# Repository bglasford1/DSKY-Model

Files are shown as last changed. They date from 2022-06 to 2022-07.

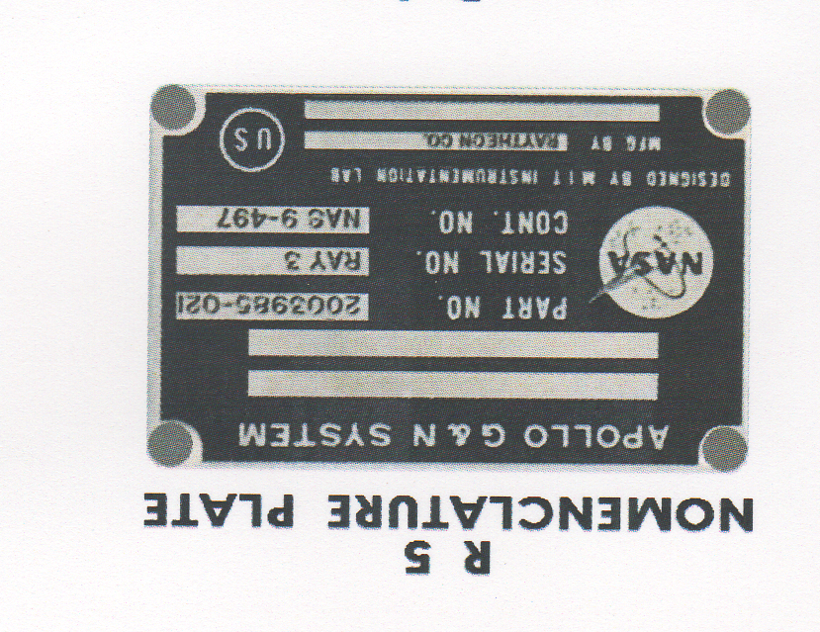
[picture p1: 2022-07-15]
NamePlate.tiff

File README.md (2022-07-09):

# DSKY-Model

This project works in conjunction with the AGC project.  The DSKY is the display/keyboard for the AGC.  As part of the AGC project, my first attempt at a DSKY was functional but not pretty.  I decided to 3D print an exact model of the DSKY and imbed the required electronics.  Instead of using LED indicators and 7-segment LEDs I chose to use a pair of LCD displays which makes the model much cleaner.  I could have placed the guts of the AGC DSKY into this model but I chose instead to drive the LCD displays and keyboard with three Arduino Nano Everys and drive those with a Raspberry Pi.  This gives me the ability to use this model as both a display for the AGC and as a standalone demonstrator by imbedding my simulator code.  The code will first look for a pulse on the CLK1 pin.  If the clock is present then it will use the Channel Bus and controls from the AGC.  If not it will start the simulator and run the simulation.  

To compile the Java code for the Raspberry Pi you need to include the pi4j (tested with version 1.2) and the jSerialComm (tested with version 2.9.1) libraries.
To compile the Arduino code you need to include the Adafruit_GFX and Adafruit_HX8357 libraries.

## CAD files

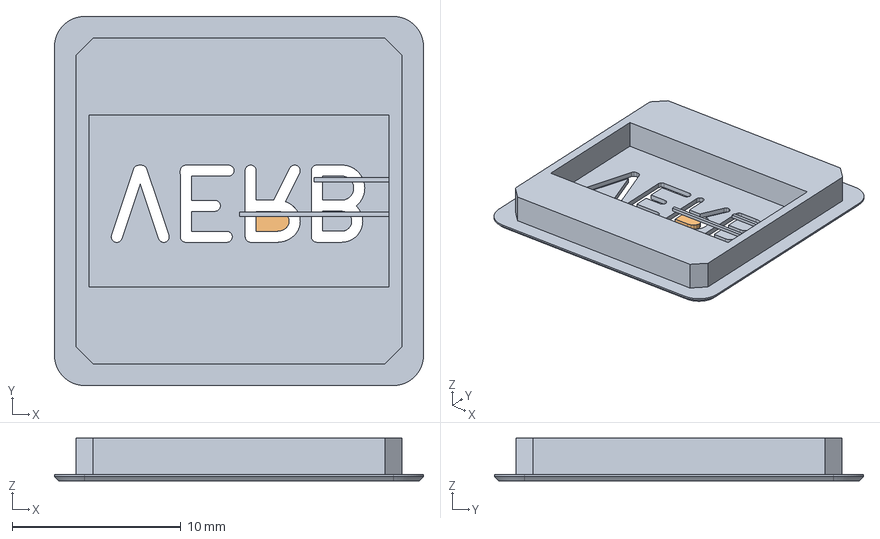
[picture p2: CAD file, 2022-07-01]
CAD/Keys/KeyVerb.step
21.8 x 21.8 x 2.54 mm

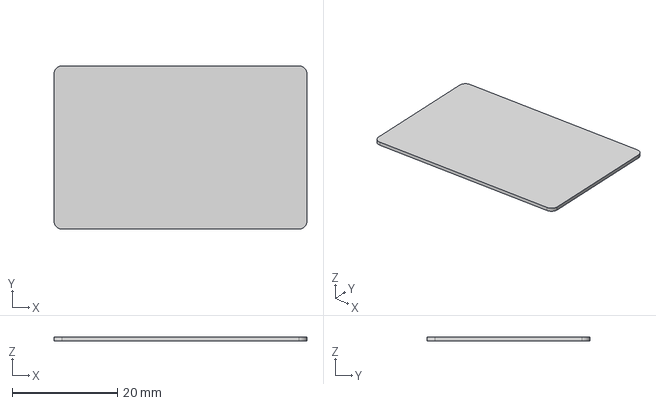
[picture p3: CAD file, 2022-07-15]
CAD/NamePlate.step
48.0 x 31.0 x 0.762 mm

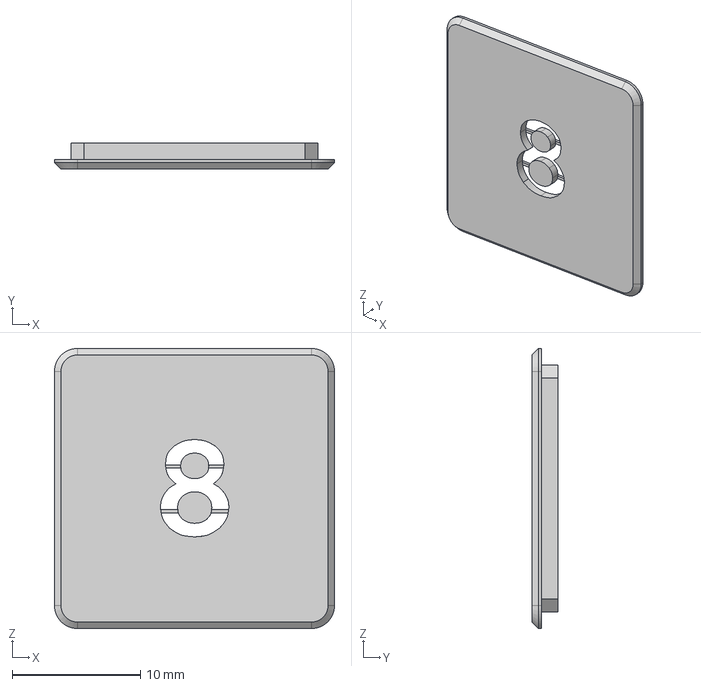
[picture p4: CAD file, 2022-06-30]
CAD/Keys/Key8.step
21.8 x 2.03 x 21.8 mm

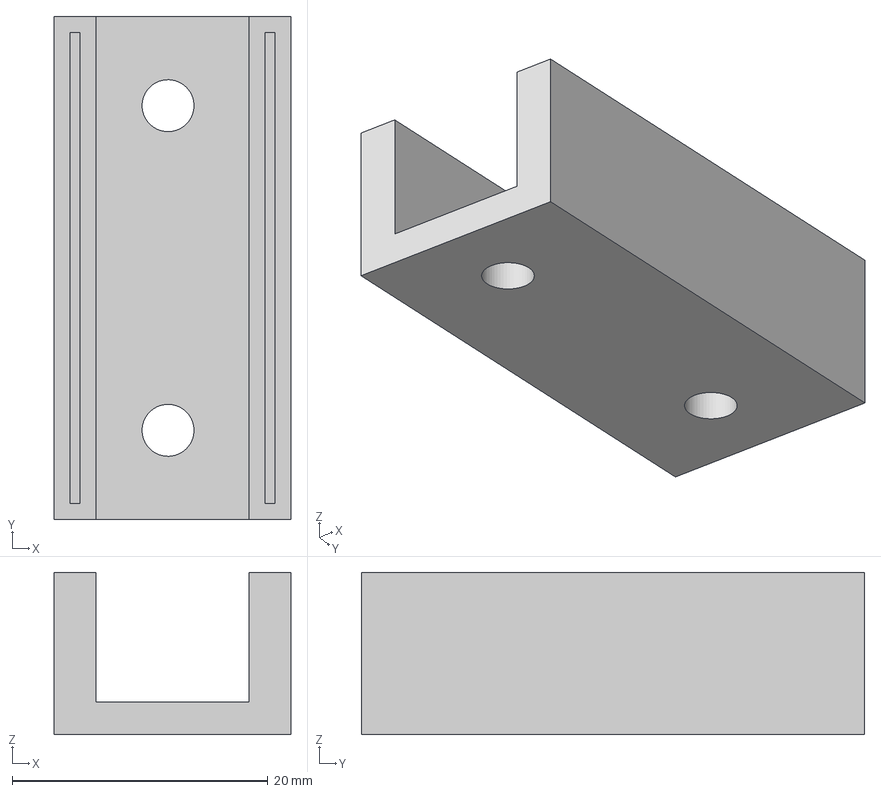
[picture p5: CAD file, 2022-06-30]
CAD/ArduinoMount.step
18.5 x 39.4 x 12.7 mm

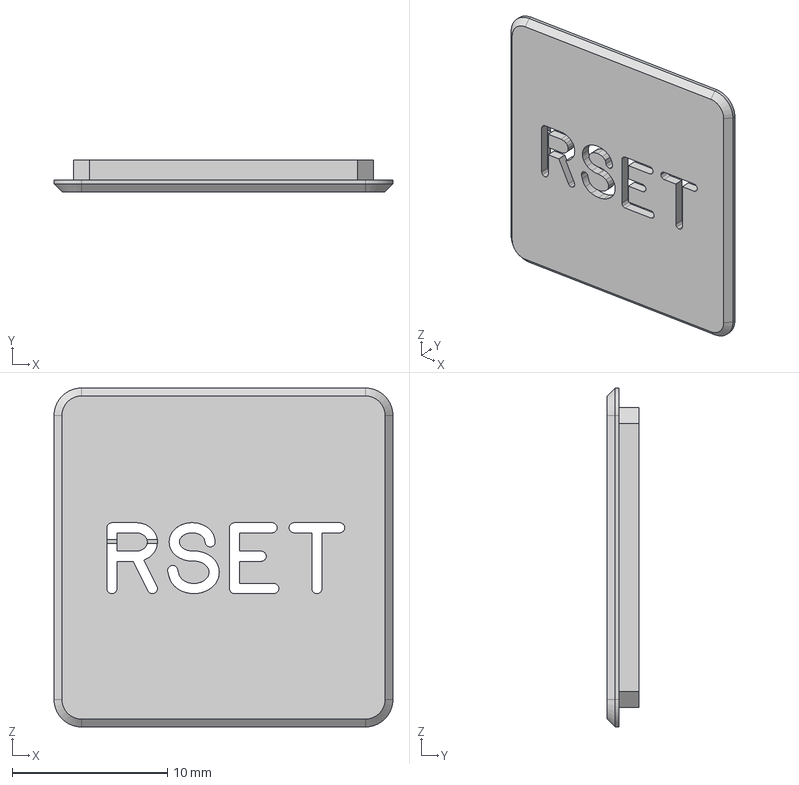
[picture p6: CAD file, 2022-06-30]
CAD/Keys/KeyReset.step
21.8 x 2.03 x 21.8 mm

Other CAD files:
CAD/Keys/KeyMinus.step
CAD/Keys/KeyPlus.step
CAD/Keys/KeyRelease.step
CAD/Keys/KeyProceed.step
CAD/Keys/KeyClear.step
CAD/Keys/KeyEnter.step
CAD/Keys/KeyNoun.step
CAD/Keys/Key7.step
CAD/Keys/Key2.step
CAD/Keys/Key3.step
CAD/Keys/Key4.step
CAD/Keys/Key5.step
CAD/Keys/Key1.step
CAD/1006315G-Modified.f3d
CAD/1006315G-Modified.step
CAD/1006349-exact-GASKET, RETAINED.f3d
CAD/1006349-exact-GASKET, RETAINED.step
CAD/1006350A-exact-GASKET, RETAINED.f3d
CAD/1006350A-exact-GASKET, RETAINED.step
CAD/1006351A-exact-GASKET.f3d
CAD/1006351A-exact-GASKET.step
CAD/2003926-reconstructed-HOUSING.step
CAD/2004699A-Modified.f3d
CAD/2004699A-Modified.step
CAD/2004900-exact-COVER,REAR.step
CAD/2004919E-modified-PLATE, ADAPTER.step
CAD/2004929-exact-COVER, FRONT.step
CAD/2004948B-modified-SHAFT.step
CAD/2004949D-exact-HOUSING.f3d
CAD/2004949D-exact-HOUSING.step
CAD/2004968E-modified.f3d
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

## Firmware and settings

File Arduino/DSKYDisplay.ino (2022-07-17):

/*
 * Copyright 2022, William Glasford
 *
 *  DSKY:
 *
 *  This is the Arduino code to run the 3.5" LCD that displays the main display of the DSKY.  
 *  This slave processor deals with the display minutia and does not store any state information.
 *  The code waits for a command from the higher level Raspberry Pi and executes the command.
 *  The display is 320 x 480 pixels in size.
 *
 * Mods:     07/04/22  Initial Release.
 *           07/16/22  Performance improvements.
 */
#include <SPI.h>
#include "Adafruit_GFX.h"
#include "Adafruit_HX8357.h"

// These are 'flexible' lines that can be changed
#define TFT_CS 8
#define TFT_DC 9
#define TFT_RST -1 // RST can be set to -1 if you tie it to Arduino's reset

#define BLACK 0x0000
#define GREEN 0x07E0 
#define WHITE 0xFFFF 
#define GREY 0x3186

#define CA_WIDTH 100
#define CA_HEIGHT 100
#define CA_COL 10
#define CA_ROW 0
#define CA_TEXT_X 38
#define CA_TEXT_Y1 30
#define CA_TEXT_Y2 50

#define PG_WIDTH 100
#define PG_HEIGHT 22
#define PG_COL 200
#define PG_ROW 0
#define PG_TEXT_X 225
#define PG_TEXT_Y 5

#define VB_WIDTH 100
#define VB_HEIGHT 22
#define VB_COL 10
#define VB_ROW 110
#define VB_TEXT_X 35
#define VB_TEXT_Y 113

#define NO_WIDTH 100
#define NO_HEIGHT 22
#define NO_COL 200
#define NO_ROW 110
#define NO_TEXT_X 225
#define NO_TEXT_Y 113

#define LINE_WIDTH 290
#define LINE_HEIGHT 7
#define LINE_COL 15
#define LINE_1_ROW 217
#define LINE_2_ROW 307
#define LINE_3_ROW 397

#define SIGN_WIDTH 30
#define SIGN_HEIGHT 10
#define R1S_ROW 261
#define R1S_COL 0
#define R2S_ROW 351
#define R2S_COL 0
#define R3S_ROW 441
#define R3S_COL 0

#define CHAR_WIDTH 45
#define CHAR_HEIGHT 70
#define CHAR_OFFSET 15
#define CHAR_BAR_WIDTH 8
#define CHAR_VOID_WIDTH 2

#define MD1_ROW 30
#define MD1_COL 195
#define MD2_ROW 30
#define MD2_COL 250

#define VD1_ROW 140
#define VD1_COL 0
#define VD2_ROW 140
#define VD2_COL 55

#define ND1_ROW 140
#define ND1_COL 195
#define ND2_ROW 140
#define ND2_COL 250

#define R1D1_ROW 230
#define R1D1_COL 30
#define R1D2_ROW 230
#define R1D2_COL 85
#define R1D3_ROW 230
#define R1D3_COL 140
#define R1D4_ROW 230
#define R1D4_COL 195
#define R1D5_ROW 230
#define R1D5_COL 250

#define R2D1_ROW 320
#define R2D1_COL 30
#define R2D2_ROW 320
#define R2D2_COL 85
#define R2D3_ROW 320
#define R2D3_COL 140
#define R2D4_ROW 320
#define R2D4_COL 195
#define R2D5_ROW 320
#define R2D5_COL 250

#define R3D1_ROW 410
#define R3D1_COL 30
#define R3D2_ROW 410
#define R3D2_COL 85
#define R3D3_ROW 410
#define R3D3_COL 140
#define R3D4_ROW 410
#define R3D4_COL 195
#define R3D5_ROW 410
#define R3D5_COL 250

#define R1S_PLUS  10
#define R1S_MINUS 11
#define R2S_PLUS  20
#define R2S_MINUS 21
#define R3S_PLUS  30
#define R3S_MINUS 31

// Use hardware SPI (on Uno, #13, #12, #11) and the above for CS/DC
Adafruit_HX8357 tft = Adafruit_HX8357(TFT_CS, TFT_DC, TFT_RST);

bool r1sPlus = false;
bool r1sMinus = false;
bool r2sPlus = false;
bool r2sMinus = false;
bool r3sPlus = false;
bool r3sMinus = false;

int vd1 = 0;
int vd2 = 0;
int nd1 = 0;
int nd2 = 0;

void setup() 
{
  String commandString;
  
  Serial.begin(9600);

  // Set up LCD
  tft.begin();
  tft.setRotation(2);

  resetDisplay();
  delay(500);

  // Wait for an initialize command.
  bool initialized = false;
  while (!initialized)
  {
    while (Serial.available()) 
    {
      delay(2);  // Delay 2 milliseconds to allow byte to arrive in input buffer
      char c = Serial.read();  // Gets one byte from serial buffer
    
      if (c != '\n' && c != '\r')  
        commandString += c; 
    }

    if (commandString.length() > 0 && commandString.equals("2"))
    {
      Serial.println("Display");
      initialized = true;
    }
    commandString = "";
  }
}

/*
 * This is the main Arduino loop that runs continuously.  It waits for a command from the 
 * Raspberry Pi, then executes the command before waiting for the next command.  Each 
 * command is followed by a number representing the 15-bit channel value.  The COMP ACTY 
 * is followed by 0 = off or 1 = on.  
 * The commands are:
 * 
 * 0  = Noop
 * 1  = Reset to power on state
 * 2  = Identify
 * 3  = Display Command
 * 4 = COMP ACTY
 * 5 = Flash Verb/Noun
 */
void loop() 
{
  String commandString;
  
  // Read the next command sequence.
  while (Serial.available()) 
  {
    delay(2);  // Delay 2 milliseconds to allow byte to arrive in input buffer
    char c = Serial.read();  // Gets one byte from serial buffer
    
    if (c != '\n')  
      commandString += c; 
  }

  // If there is a command string to parse...
  if (commandString.length() > 0) 
  {
    String command = commandString;
    String data = "";
    String delim = " ";
    int number;
    byte dspl;
    byte dsph;
    byte rlwd;
    bool signValue = false;

    // Parse the command string.
    if (commandString != "0" && commandString != "1" && commandString != "2")
    {
      int firstDelimIndex = commandString.indexOf(delim);
      command = commandString.substring(0, firstDelimIndex);
      data = commandString.substring(firstDelimIndex + 1);
      int intValue = data.toInt();
      Serial.println(intValue);
      rlwd = (intValue >> 11) & 0x000F;
      dspl = intValue & 0x001F;
      dsph = (intValue >> 5) & 0x001F;
      signValue = (intValue >> 10) & 0x0001;
     }
    
    // Process the Reset command.
    if (command == "1")
    {
      resetDisplay();
    }

    // Process the MD1/MD2 command.
    else if (command == "3")
    {
      if (rlwd == 11)
      {
        displayCharacter(dsph, MD1_COL, MD1_ROW);
        displayCharacter(dspl, MD2_COL, MD2_ROW);
      }
      else if (rlwd == 10)
      {
        vd1 = dspl;
        vd2 = dsph;
        displayCharacter(dsph, VD1_COL, VD1_ROW);
        displayCharacter(dspl, VD2_COL, VD2_ROW);
      }
      else if (rlwd == 9)
      {
        nd1 = dspl;
        nd2 = dsph;
        displayCharacter(dsph, ND1_COL, ND1_ROW);
        displayCharacter(dspl, ND2_COL, ND2_ROW);
      }
      else if (rlwd == 8)
      {
        displayCharacter(dspl, R1D1_COL, R1D1_ROW);
      }
      else if (rlwd == 7)
      {
        if (signValue)
        {
          r1sPlus = true;
          if (!r1sMinus)
          {
            displayPlus(R1S_COL, R1S_ROW);
          }
        }
        else
        {
          r1sPlus = false;
          if (!r1sMinus)
          {
            displayBlank(R1S_COL, R1S_ROW);
          }
        }
        displayCharacter(dsph, R1D2_COL, R1D2_ROW);
        displayCharacter(dspl, R1D3_COL, R1D3_ROW);
      }
      else if (rlwd == 6)
      {
        if (signValue)
        {
          r1sMinus = true;
          if (!r1sPlus)
          {
            displayMinus(R1S_COL, R1S_ROW);
          }
        }
        else
        {
          r1sMinus = false;
          if (!r1sPlus)
          {
            displayBlank(R1S_COL, R1S_ROW);
          }
        }
        displayCharacter(dsph, R1D4_COL, R1D4_ROW);
        displayCharacter(dspl, R1D5_COL, R1D5_ROW);
      }
      else if (rlwd == 5)
      {
        if (signValue)
        {
          r2sPlus = true;
          if (!r2sMinus)
          {
            displayPlus(R2S_COL, R2S_ROW);
          }
        }
        else
        {
          r2sPlus = false;
          if (!r2sMinus)
          {
            displayBlank(R2S_COL, R2S_ROW);
          }
        }
        displayCharacter(dsph, R2D1_COL, R2D1_ROW);
        displayCharacter(dspl, R2D2_COL, R2D2_ROW);
      }
      else if (rlwd == 4)
      {
        if (signValue)
        {
          r2sMinus = true;
          if (!r2sPlus)
          {
            displayMinus(R2S_COL, R2S_ROW);
          }
        }
        else
        {
          r2sMinus = false;
          if (!r2sPlus)
          {
            displayBlank(R2S_COL, R2S_ROW);
          }
        }
        displayCharacter(dsph, R2D3_COL, R2D3_ROW);
        displayCharacter(dspl, R2D4_COL, R2D4_ROW);
      }
      else if (rlwd == 3)
      {
        displayCharacter(dsph, R2D5_COL, R2D5_ROW);
        displayCharacter(dspl, R3D1_COL, R3D1_ROW);
      }
      else if (rlwd == 2)
      {
        if (signValue)
        {
          r3sPlus = true;
          if (!r3sMinus)
          {
            displayPlus(R3S_COL, R3S_ROW);
          }
        }
        else
        {
          r3sPlus = false;
          if (!r3sMinus)
          {
            displayBlank(R3S_COL, R3S_ROW);
          }
        }
        displayCharacter(dsph, R3D2_COL, R3D2_ROW);
        displayCharacter(dspl, R3D3_COL, R3D3_ROW);
      }
      else if (rlwd == 1)
      {
        if (signValue)
        {
          r3sMinus = true;
          if (!r3sPlus)
          {
            displayMinus(R3S_COL, R3S_ROW);
          }
        }
        else
        {
          r3sMinus = false;
          if (!r3sPlus)
          {
            displayBlank(R3S_COL, R3S_ROW);
          }
        }
        displayCharacter(dsph, R3D4_COL, R3D4_ROW);
        displayCharacter(dspl, R3D5_COL, R3D5_ROW);
      }
    }

    // Process the COMP ACTY command.
    else if (command == "4")
    {
      if (data == "0")
      {
        displayCompActy(false);
      }
      else
      {
        displayCompActy(true);
      }
    }

    // Process Flash Verb/Noun command.
    else if (command = "5")
    {
      if (data == "0")
      {
        displayCharacter(0, VD1_COL, VD1_ROW);
        displayCharacter(0, VD2_COL, VD2_ROW);
        displayCharacter(0, ND1_COL, ND1_ROW);
        displayCharacter(0, ND2_COL, ND2_ROW);
      }
      else 
      {
        displayCharacter(vd1, VD1_COL, VD1_ROW);
        displayCharacter(vd2, VD2_COL, VD2_ROW);
        displayCharacter(nd1, ND1_COL, ND1_ROW);
        displayCharacter(nd2, ND2_COL, ND2_ROW);
      }
    }

    commandString = "";
  }
}

/*
 * Reset the display to a power on state.
 */
void resetDisplay()
{
  tft.fillScreen(BLACK);  
  tft.setTextColor(BLACK);
  tft.setTextSize(2);

  // Display PROG 
  tft.fillRect(PG_COL, PG_ROW, PG_WIDTH, PG_HEIGHT, GREEN);
  
  tft.setTextColor(BLACK);
  tft.setTextSize(2);
    
  tft.setCursor(PG_TEXT_X, PG_TEXT_Y);
  tft.println("PROG");

  // Display VERB 
  tft.fillRect(VB_COL, VB_ROW, VB_WIDTH, VB_HEIGHT, GREEN);
  
  tft.setTextColor(BLACK);
  tft.setTextSize(2);
    
  tft.setCursor(VB_TEXT_X, VB_TEXT_Y);
  tft.println("VERB");

  // Display NOUN 
  tft.fillRect(NO_COL, NO_ROW, PG_WIDTH, NO_HEIGHT, GREEN);
  
  tft.setTextColor(BLACK);
  tft.setTextSize(2);
    
  tft.setCursor(NO_TEXT_X, NO_TEXT_Y);
  tft.println("NOUN");

  // Display Lines 
  tft.fillRect(LINE_COL, LINE_1_ROW, LINE_WIDTH, LINE_HEIGHT, GREEN);
  tft.fillRect(LINE_COL, LINE_2_ROW, LINE_WIDTH, LINE_HEIGHT, GREEN);
  tft.fillRect(LINE_COL, LINE_3_ROW, LINE_WIDTH, LINE_HEIGHT, GREEN);

  displayCompActy(false);
}

/*
 * Turn on/off the Computer Activity light.  
 */
void displayCompActy(bool state)
{
  if (state)
  {
    tft.fillRect(CA_COL, CA_ROW, CA_WIDTH, CA_HEIGHT, GREEN);
  }
  else
  {
    tft.fillRect(CA_COL, CA_ROW, CA_WIDTH, CA_HEIGHT, GREY);
  }
    
  tft.setCursor(CA_TEXT_X, CA_TEXT_Y1);
  tft.println("COMP");
 
  tft.setCursor(CA_TEXT_X, CA_TEXT_Y2);
  tft.println("ACTY");
}

/*
 * Display the character based on home position (upper left corner).  There are two triangles used
 * to draw each segment.  The first one draws from UL, LL & LR.  The second one draws from UL, UR & LR.
 */
 void displayCharacter(byte number, int x, int y)
 {
  // Display based on character to display.
  if (number == 0x00) // Blank
  {
    drawSegmentA(x, y, BLACK);
    drawSegmentB(x, y, BLACK);
    drawSegmentC(x, y, BLACK);
    drawSegmentD(x, y, BLACK);
    drawSegmentE(x, y, BLACK);
    drawSegmentF(x, y, BLACK);
    drawSegmentG(x, y, BLACK);
  }
  else if (number == 0x15) // 0
  {
    drawSegmentA(x, y, GREEN);
    drawSegmentB(x, y, GREEN);
    drawSegmentC(x, y, GREEN);
    drawSegmentD(x, y, GREEN);
    drawSegmentE(x, y, GREEN);
    drawSegmentF(x, y, GREEN);
    drawSegmentG(x, y, BLACK);
  }
  else if (number == 0x03) // 1
  {
    drawSegmentA(x, y, BLACK);
    drawSegmentB(x, y, GREEN);
    drawSegmentC(x, y, GREEN);
    drawSegmentD(x, y, BLACK);
    drawSegmentE(x, y, BLACK);
    drawSegmentF(x, y, BLACK);
    drawSegmentG(x, y, BLACK);
  }
  else if (number == 0x19) // 2
  {
    drawSegmentA(x, y, GREEN);
    drawSegmentB(x, y, GREEN);
    drawSegmentC(x, y, BLACK);
    drawSegmentE(x, y, GREEN);
    drawSegmentD(x, y, GREEN);
    drawSegmentF(x, y, BLACK);
    drawSegmentG(x, y, GREEN);
  }
  else if (number == 0x1B) // 3
  {
    drawSegmentA(x, y, GREEN);
    drawSegmentB(x, y, GREEN);
    drawSegmentC(x, y, GREEN);
    drawSegmentD(x, y, GREEN);
    drawSegmentE(x, y, BLACK);
    drawSegmentF(x, y, BLACK);
    drawSegmentG(x, y, GREEN);
  }
  else if (number == 0x0F) // 4
  {
    drawSegmentA(x, y, BLACK);
    drawSegmentB(x, y, GREEN);
    drawSegmentC(x, y, GREEN);
    drawSegmentD(x, y, BLACK);
    drawSegmentE(x, y, BLACK);
    drawSegmentF(x, y, GREEN);
    drawSegmentG(x, y, GREEN);
  }
  else if (number == 0x1E) // 5
  {
    drawSegmentA(x, y, GREEN);
    drawSegmentB(x, y, BLACK);
    drawSegmentC(x, y, GREEN);
    drawSegmentD(x, y, GREEN);
    drawSegmentE(x, y, BLACK);
    drawSegmentF(x, y, GREEN);
    drawSegmentG(x, y, GREEN);
  }
  else if (number == 0x1C) // 6
  {
    drawSegmentA(x, y, GREEN);
    drawSegmentB(x, y, BLACK);
    drawSegmentC(x, y, GREEN);
    drawSegmentD(x, y, GREEN);
    drawSegmentE(x, y, GREEN);
    drawSegmentF(x, y, GREEN);
    drawSegmentG(x, y, GREEN);
  }
  else if (number == 0x13) // 7
  {
    drawSegmentA(x, y, GREEN);
    drawSegmentB(x, y, GREEN);
    drawSegmentC(x, y, GREEN);
    drawSegmentD(x, y, BLACK);
    drawSegmentE(x, y, BLACK);
    drawSegmentF(x, y, BLACK);
    drawSegmentG(x, y, BLACK);
  }
  else if (number == 0x1D) // 8
  {
    drawSegmentA(x, y, GREEN);
    drawSegmentB(x, y, GREEN);
    drawSegmentC(x, y, GREEN);
    drawSegmentD(x, y, GREEN);
    drawSegmentE(x, y, GREEN);
    drawSegmentF(x, y, GREEN);
    drawSegmentG(x, y, GREEN);
  }
  else if (number == 0x1F) // 9
  {
    drawSegmentA(x, y, GREEN);
    drawSegmentB(x, y, GREEN);
    drawSegmentC(x, y, GREEN);
    drawSegmentD(x, y, BLACK);
    drawSegmentE(x, y, BLACK);
    drawSegmentF(x, y, GREEN);
    drawSegmentG(x, y, GREEN);
  }
  else
  {
    displayCompActy(true);
  }
}

/*
 * Draw the A segment of the 7-segment LED.
 */
void drawSegmentA (int x, int y, int color)
{
  tft.fillTriangle (x + CHAR_OFFSET + 1, y, 
                    x + CHAR_OFFSET + CHAR_BAR_WIDTH, y + CHAR_BAR_WIDTH, 
                    x + CHAR_OFFSET + CHAR_WIDTH - CHAR_BAR_WIDTH - 2, y + CHAR_BAR_WIDTH, color);
 
  tft.fillTriangle (x + CHAR_OFFSET + 1, y,
                    x + CHAR_OFFSET + CHAR_WIDTH - CHAR_BAR_WIDTH - 2, y, 
                    x + CHAR_OFFSET + CHAR_WIDTH - CHAR_BAR_WIDTH - 4, y + CHAR_BAR_WIDTH, color); 
}

/*
 * Draw the B segment of the 7-segment LED.
 */
void drawSegmentB (int x, int y, int color)
{
  tft.fillTriangle (x + CHAR_OFFSET + CHAR_WIDTH - CHAR_BAR_WIDTH, y, 
                    x + CHAR_WIDTH, y + 34, 
                    x + CHAR_WIDTH + CHAR_BAR_WIDTH, y + 34, color);
 
  tft.fillTriangle (x + CHAR_OFFSET + CHAR_WIDTH - CHAR_BAR_WIDTH, y,
                    x + CHAR_OFFSET + CHAR_WIDTH, y, 
                    x + CHAR_WIDTH + CHAR_BAR_WIDTH, y + 34, color);
}

/*
 * Draw the C segment of the 7-segment LED.
 */
void drawSegmentC (int x, int y, int color)
{
  tft.fillTriangle (x + CHAR_OFFSET + CHAR_WIDTH - CHAR_BAR_WIDTH - 8, y + 36, 
                    x + CHAR_WIDTH - CHAR_BAR_WIDTH + 2, y + CHAR_HEIGHT - CHAR_BAR_WIDTH - 2, 
                    x + CHAR_WIDTH, y + CHAR_HEIGHT, color);
 
  tft.fillTriangle (x + CHAR_OFFSET + CHAR_WIDTH - CHAR_BAR_WIDTH - 8, y + 36,
                    x + CHAR_OFFSET + CHAR_WIDTH - 7, y + 36, 
                    x + CHAR_WIDTH, y + CHAR_HEIGHT, color);
}

/*
 * Draw the D segment of the 7-segment LED.
 */
void drawSegmentD (int x, int y, int color)
{
  tft.fillTriangle (x + CHAR_BAR_WIDTH + 4, y + CHAR_HEIGHT - CHAR_BAR_WIDTH, 
                    x + 2, y + CHAR_HEIGHT, 
                    x + CHAR_WIDTH - 2, y + CHAR_HEIGHT, color);
 
  tft.fillTriangle (x + CHAR_BAR_WIDTH + 4, y + CHAR_HEIGHT - CHAR_BAR_WIDTH,
                    x + CHAR_WIDTH - CHAR_BAR_WIDTH, y + CHAR_HEIGHT - CHAR_BAR_WIDTH, 
                    x + CHAR_WIDTH - 2, y + CHAR_HEIGHT, color);
}

/*
 * Draw the E segment of the 7-segment LED.
 */
void drawSegmentE (int x, int y, int color)
{
  tft.fillTriangle (x + 7, y + 36, 
                    x, y + CHAR_HEIGHT - 1, 
                    x + CHAR_BAR_WIDTH + 1, y + CHAR_HEIGHT - CHAR_BAR_WIDTH, color);
 
  tft.fillTriangle (x + 7, y + 36,
                    x + CHAR_BAR_WIDTH + 7, y + 36, 
                    x + CHAR_BAR_WIDTH + 1, y + CHAR_HEIGHT - CHAR_BAR_WIDTH, color);
}

/*
 * Draw the F segment of the 7-segment LED.
 */
void drawSegmentF (int x, int y, int color)
{
  tft.fillTriangle (x + CHAR_OFFSET - 1, y, 
                    x + 7, y + 34, 
                    x + CHAR_BAR_WIDTH + 7, y + 34, color);
 
  tft.fillTriangle (x + CHAR_OFFSET - 1, y,
                    x + CHAR_OFFSET + CHAR_BAR_WIDTH - 2, y + CHAR_BAR_WIDTH + 2, 
                    x + CHAR_BAR_WIDTH + 7, y + 34, color);
}

/*
 * Draw the G segment of the 7-segment LED.
 */
void drawSegmentG (int x, int y, int color)
{
  tft.fillTriangle (x + CHAR_OFFSET + CHAR_BAR_WIDTH - 4, y + 31, 
                    x + CHAR_OFFSET + CHAR_BAR_WIDTH - 6, y + 39, 
                    x + CHAR_WIDTH - CHAR_BAR_WIDTH + 4, y + 39, color);
 
  tft.fillTriangle (x + CHAR_OFFSET + CHAR_BAR_WIDTH - 4, y + 31,
                    x + CHAR_WIDTH - CHAR_BAR_WIDTH + 6, y + 31, 
                    x + CHAR_WIDTH - CHAR_BAR_WIDTH + 4, y + 39, color);
}

/*
 * Display the plus sign.
 */
void displayPlus (int x, int y)
{
  tft.fillRect(x, y, SIGN_WIDTH, SIGN_HEIGHT, GREEN);
  tft.fillRect(x + 11, y - 17, 8, 14, GREEN);
  tft.fillRect(x + 11, y + 13, 8, 14, GREEN);
}

/*
 * Display the minus sign.
 */
void displayMinus (int x, int y)
{
  tft.fillRect(x, y, SIGN_WIDTH, SIGN_HEIGHT, GREEN);
  tft.fillRect(x + 11, y - 17, 8, 14, BLACK);
  tft.fillRect(x + 11, y + 13, 8, 14, BLACK);
}

/*
 * Blank the sign.
 */
void displayBlank (int x, int y)
{
  tft.fillRect(x, y, SIGN_WIDTH, SIGN_HEIGHT, BLACK);
  tft.fillRect(x + 11, y - 17, 8, 14, BLACK);
  tft.fillRect(x + 11, y + 13, 8, 14, BLACK);
}

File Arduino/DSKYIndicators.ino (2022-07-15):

/*
 * Copyright 2022, William Glasford
 *
 *  DSKY:
 *
 *  This is the Arduino code to run the 3.5" LCD that displays the indicators of the DSKY.  
 *  This slave processor deals with the display minutia and does not store any state information.
 *  The code waits for a command from the higher level Raspberry Pi and executes the command.
 *
 * Mods:     07/04/22  Initial Release.
 *           07/15/22  Simplified commands to take 6 indicators at a time.
 */
#include <SPI.h>
#include "Adafruit_GFX.h"
#include "Adafruit_HX8357.h"

// These are 'flexible' lines that can be changed
#define TFT_CS 8
#define TFT_DC 9
#define TFT_RST -1 // RST can be set to -1 if you tie it to Arduino's reset

// LCD colors: RGB: 16-bit value from MSB to LSB: RRRRRGGGGGGBBBBB
#define BLACK 0x0000
#define WHITE 0xFFFF 
#define GREY 0x3186
#define YELLOW 0xFFE0

#define BOX_WIDTH 156
#define BOX_HEIGHT 60
#define START_COL1 0
#define START_COL2 164
#define START_ROW1 0
#define START_ROW2 68
#define START_ROW3 136
#define START_ROW4 204
#define START_ROW5 272
#define START_ROW6 340
#define START_ROW7 408
#define TEXT_UPPER_ROW 15
#define TEXT_LOWER_ROW 35
#define TEXT_CENTERED 25
#define TEXT_SHORT 60
#define TEXT_MEDIUM 55
#define TEXT_LONG 45
#define TEXT_XLONG 35

// Use hardware SPI (on Uno, #13, #12, #11) and the above for CS/DC
Adafruit_HX8357 tft = Adafruit_HX8357(TFT_CS, TFT_DC, TFT_RST);

// SoftSPI - note that on some processors this might be *faster* than hardware SPI!
//Adafruit_HX8357 tft = Adafruit_HX8357(TFT_CS, TFT_DC, MOSI, SCK, TFT_RST, MISO);

int savedDisplayIndicators = 0;
int savedOtherIndicators = 0;

void setup() 
{
  String commandString;
  
  Serial.begin(9600);

  // TODO: Set up LCD
  tft.begin();
  tft.setRotation(2);

  resetDisplay();
  delay(100);

  // Wait for an initialize command.
  bool initialized = false;
  while (!initialized)
  {
    while (Serial.available()) 
    {
      delay(2);  // Delay 2 milliseconds to allow byte to arrive in input buffer
      char c = Serial.read();  // Gets one byte from serial buffer
    
      if (c != '\n' && c != '\r')  
        commandString += c; 
    }

    if (commandString.length() > 0 && commandString.equals("2"))
    {
      Serial.println("Indicators");
      initialized = true;
    }
    commandString = "";
  }
}

/*
 * This is the main Arduino loop that runs continuously.  It waits for a command from the 
 * Raspberry Pi, then executes the command before waiting for the next command.  Commands 
 * 3 & 4 are followed by an integer string that represents the bits as defined below.
 * The commands are:
 * 0  = Noop
 * 1  = Reset to power on state
 * 2  = Identify
 * 3  = Display Indicators
 *        Bit 0 = NO ATT
 *        Bit 1 = GIMBAL LOCK
 *        Bit 2 = PROG
 *        Bit 3 = TRACKER
 *        Bit 4 = ALT
 *        Bit 5 = VEL
 * 4  = Other Indicators
 *        Bit 0 = UPLINK ACTY
 *        Bit 1 = KEY REL
 *        Bit 2 = OPR ERR
 *        Bit 3 = TEMP
 *        Bit 4 = STBY
 *        Bit 5 = RESTART
 */
void loop() 
{
  String commandString;

  // Read the next command sequence.
  while (Serial.available() > 0) 
  {
    delay(2);  // Delay 2 milliseconds to allow byte to arrive in input buffer
    char c = Serial.read();  // Gets one byte from serial buffer
    
    if (c != '\n' && c != '\r')  
      commandString += c; 
  }

  // If there is a command string to parse...
  if (commandString.length() > 0) 
  {
    String command = commandString;
    String data = "";
    String delim = " ";

    // Parse the command string.
    if (commandString != "0" && commandString != "1" && commandString != "2")
    {
      int firstDelimIndex = commandString.indexOf(delim);
      command = commandString.substring(0, firstDelimIndex);
      data = commandString.substring(firstDelimIndex + 1, commandString.length());
    }
    
    // Process the Reset command.
    if (command == "1")
    {
     resetDisplay();
    }
    
    // Process the Display Indicators command.
    else if (command == "3")
    {
      byte newDisplayValue = (byte)data.toInt();
      byte bitZero  = newDisplayValue & 0x01;
      byte bitOne   = (newDisplayValue >> 1) & 0x01;
      byte bitTwo   = (newDisplayValue >> 2) & 0x01;
      byte bitThree = (newDisplayValue >> 3) & 0x01;
      byte bitFour  = (newDisplayValue >> 4) & 0x01;
      byte bitFive  = (newDisplayValue >> 5) & 0x01;
      
      byte oldBitZero  = savedDisplayIndicators & 0x01;
      byte oldBitOne   = (savedDisplayIndicators >> 1) & 0x01;
      byte oldBitTwo   = (savedDisplayIndicators >> 2) & 0x01;
      byte oldBitThree = (savedDisplayIndicators >> 3) & 0x01;
      byte oldBitFour  = (savedDisplayIndicators >> 4) & 0x01;
      byte oldBitFive  = (savedDisplayIndicators >> 5) & 0x01;

      if (bitZero != oldBitZero)
      {
        drawNOATT(bitZero);
      }
      if (bitOne != oldBitOne)
      {
        drawGIMBALLOCK(bitOne);
      }
      if (bitTwo != oldBitTwo)
      {
        drawPROG(bitTwo);
      }
      if (bitThree != oldBitThree)
      {
        drawTRACKER(bitThree);
      }
      if (bitFour != oldBitFour)
      {
        drawALT(bitFour);
      }
      if (bitFive != oldBitFive)
      {
        drawVEL(bitFive);
      }
      savedDisplayIndicators = newDisplayValue;
    }

    // Process the Other Indicators command.
    else if (command == "4")
    {
      byte newOtherValue = (byte)data.toInt();
      byte bitZero  = newOtherValue & 0x01;
      byte bitOne   = (newOtherValue >> 1) & 0x01;
      byte bitTwo   = (newOtherValue >> 2) & 0x01;
      byte bitThree = (newOtherValue >> 3) & 0x01;
      byte bitFour  = (newOtherValue >> 4) & 0x01;
      byte bitFive  = (newOtherValue >> 5) & 0x01;
      
      byte oldBitZero  = savedOtherIndicators & 0x01;
      byte oldBitOne   = (savedOtherIndicators >> 1) & 0x01;
      byte oldBitTwo   = (savedOtherIndicators >> 2) & 0x01;
      byte oldBitThree = (savedOtherIndicators >> 3) & 0x01;
      byte oldBitFour  = (savedOtherIndicators >> 4) & 0x01;
      byte oldBitFive  = (savedOtherIndicators >> 5) & 0x01;

      if (bitZero != oldBitZero)
      {
        drawUPLINKACTY(bitZero);
      }
      if (bitOne != oldBitOne)
      {
        drawKEYREL(bitOne);
      }
      if (bitTwo != oldBitTwo)
      {
        drawOPRERR(bitTwo);
      }
      if (bitThree != oldBitThree)
      {
        drawTEMP(bitThree);
      }
      if (bitFour != oldBitFour)
      {
        drawSTBY(bitFour);
      }
      if (bitFive != oldBitFive)
      {
        drawRESTART(bitFive);
      }
      savedOtherIndicators = newOtherValue;
    }

    commandString = "";
  }
}
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

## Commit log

2022-06-30 Initial Upload
    [1006315G-Modified.f3d, 1006315G-Modified.step, 1006349-exact-GASKET, RETAINED.f3d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]
2022-06-30 8 key was a bit off.
    [Key8.f3d, Key8.step]
2022-07-01 Verb Key was using wrong font.
    [KeyVerb.f3d, KeyVerb.step]
2022-07-05 3 holes were missing
    [2004974D-modified-PLATE,IDM.step]
2022-07-15 Added NamePlate
    [NamePlate.f3d, NamePlate.step]
